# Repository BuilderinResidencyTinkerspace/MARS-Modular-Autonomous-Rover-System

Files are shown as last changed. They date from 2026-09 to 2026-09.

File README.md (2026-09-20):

# MARS — Modular Autonomous Rover System 🤖

> **One rover. Multiple capabilities.**

MARS (**Modular Autonomous Rover System**) is a modular robotic platform developed to explore how a single autonomous rover can be adapted for different real-world applications through interchangeable modules.

The project started with a simple question:

> **Instead of building a different robot for every task, can one rover be designed to perform multiple tasks by changing its module?**

This idea led to the development of a common rover base with autonomous movement, obstacle detection, wireless control, and interchangeable application-specific modules.

---

## 🚀 Project Overview

MARS consists of two main parts:

```text
                 ┌──────────────────────┐
                 │      MARS BASE       │
                 │      ROVER           │
                 │                      │
                 │ • Autonomous Motion  │
                 │ • Obstacle Detection │
                 │ • Wireless Control   │
                 │ • Modular Interface  │
                 └──────────┬───────────┘
                            │
             ┌──────────────┴──────────────┐
             │                             │
             ▼                             ▼
   ┌───────────────────┐       ┌────────────────────┐
   │ Raspberry Pi      │       │ Environmental      │
   │ Camera Module     │       │ Monitoring Module  │
   │                   │       │                    │
   │ • Webcam          │       │ • Gas Sensor       │
   │ • Live Streaming  │       │ • Soil Moisture    │
   │                   │       │ • Temperature      │
   └───────────────────┘       │ • Humidity         │
                               │ • Servo Mechanism  │
                               └────────────────────┘
```

The **base rover** provides mobility and autonomous navigation, while application-specific modules extend its functionality.

---

## 🎯 Objectives

The main objectives of MARS are:

* Develop a functional autonomous rover platform.
* Implement obstacle detection and avoidance.
* Enable wireless control of the rover.
* Develop a modular mechanism for attaching different application modules.
* Explore Raspberry Pi-based vision and remote monitoring.
* Develop an environmental sensing module.
* Integrate mechanical, electronic, and software systems into a single platform.
* Create a flexible platform that can be adapted for different field applications.

---

## 🛠️ Hardware

### Base Rover

| Component | Purpose |
| --- | --- |
| Arduino Uno | Main controller |
| DC Geared Motors | Rover movement |
| Motor Driver | Motor control |
| 14.8 V Battery | Main power source |
| Buck Converter | Voltage regulation |
| Ultrasonic Sensors | Obstacle detection |
| Bluetooth Module | Wireless control |
| 65 mm Universal Hub Tyres | Rover movement |
| Perfboard | Permanent circuit |
| 3D-Printed Chassis | Mechanical structure |

### Camera Module

| Component | Purpose |
| --- | --- |
| Raspberry Pi | Processing and streaming |
| Webcam | Live video capture |

### Environmental Monitoring Module

| Component | Purpose |
| --- | --- |
| Arduino Nano | Module controller |
| Gas Sensor | Gas detection |
| Soil Moisture Sensor | Soil moisture measurement |
| Temperature & Humidity Sensor | Environmental monitoring |
| Servo Motor | Raises/lowers the soil moisture sensor |

---

## ⚙️ Base Rover

The base rover went through several stages of development.

### 1. Initial Prototype

The first prototype was built using a temporary foam-board base. This allowed the basic components and movement system to be tested before developing the final mechanical structure.

### 2. Controller and Communication

The project initially used an **ESP32-S3** because of its built-in Wi-Fi capability.

During testing, the ESP32-S3 was damaged following a short circuit. We then adapted the rover to an **Arduino Uno**.

Since the Arduino Uno does not have built-in Wi-Fi, the communication system was changed from Wi-Fi-based control to **Bluetooth control**.

```text
Bluetooth Serial Terminal
            ↓
      Bluetooth Module
            ↓
        Arduino Uno
            ↓
       Motor Driver
            ↓
          Motors
```

### 3. Obstacle Detection

Three ultrasonic sensors were used at the front of the rover.

The sensors were arranged approximately as:

```text
             Front
               ↑

       \       |       /
        \      |      /
       +25°   0°   -25°

       Ultrasonic Sensors
```

This arrangement was tested to improve obstacle detection coverage in the direction of movement.

### 4. Autonomous Movement

The rover was developed to:

* Move forward
* Move backward
* Turn left
* Turn right
* Stop when an obstacle is detected
* Continue movement after the obstacle is removed

We also experimented with **point-to-point movement using a predefined room map**, testing movements such as A → B.

---

## 🔧 Mechanical Development

The mechanical structure evolved throughout the project.

The initial prototype used a **30 × 30 cm foam-board base**. Later, a more compact 3D-printed structure was developed with approximate dimensions of **21 × 18 cm**.

The CAD structure included provisions for:

* Battery mounting
* Ultrasonic sensor mounting
* Electronic component placement
* Module integration

The design was developed using **Zoo Keeper and Fusion 360**, followed by 3D printing and physical testing.

---

## 🔌 Electrical Development

The rover initially used a breadboard for temporary connections.

As the design became more stable, the circuit was transferred to a **perfboard**.

```text
Breadboard Prototype
        ↓
Component Testing
        ↓
Circuit Verification
        ↓
Perfboard
        ↓
Soldering & Wiring
        ↓
3D-Printed Integration
```

The permanent circuit contains the main control, communication, sensing, motor-control, and power-regulation components.

---

# 🧩 Application Modules

The modular architecture is the main concept behind MARS.

Instead of modifying the entire rover for every application, different modules can be attached to the same base platform.

## 📷 1. Raspberry Pi Camera Module

A Raspberry Pi and webcam were integrated as a separate module to provide **live video streaming**.

The development involved learning the Raspberry Pi setup process, including:

* Operating system installation
* Initial configuration
* Connecting the Raspberry Pi
* Connecting the webcam
* Network configuration
* Live video streaming

### System Flow

```text
       Webcam
          ↓
    Raspberry Pi
          ↓
      Wi-Fi Network
          ↓
    Live Video Stream
          ↓
     Remote User
```

This module can be used for applications such as:

* Remote inspection
* Surveillance
* Visual monitoring
* Disaster-area observation

---

## 🌱 2. Environmental Monitoring Module

The second module was developed using an **Arduino Nano**.

It combines multiple sensors to collect environmental information.

### Sensors

* Gas sensor
* Soil moisture sensor
* Temperature sensor
* Humidity sensor

A **servo motor** was also incorporated to mechanically raise and lower the soil-moisture sensor when required.

```text
Gas Sensor ─────────────┐
                        │
Soil Moisture Sensor ───┤
                        │
Temperature/Humidity ───┤
                        ↓
                    Arduino Nano
                        │
                        ↓
                   Sensor Data

                  Servo Motor
                       ↓
          Raise / Lower Moisture Sensor
```

This module demonstrates how MARS can be adapted for environmental monitoring applications.

---

# 📅 Development Timeline

| Week | Major Development |
| --- | --- |
| **Week 0** | MARS concept, system architecture and component planning |
| **Week 1** | Initial rover prototype and component procurement |
| **Week 2** | Component testing, 3D-printing and PCB design learning |
| **Week 3** | ESP32-S3 integration, Wi-Fi control and obstacle detection |
| **Week 4** | Autonomous movement experiments and sensor arrangement |
| **Week 5** | ESP32-S3 failure, Arduino Uno adaptation and Bluetooth control |
| **Week 6** | Ultrasonic integration, point-to-point navigation and CAD development |
| **Week 7** | New tyres, perfboard conversion and 3D-printed integration |
| **Week 8** | Permanent electrical system and room-based sensor testing |
| **Week 9** | Raspberry Pi camera module and environmental monitoring module |

---

# 🧠 Key Learning

The development of MARS involved learning across multiple areas:

### Electronics

* Motor drivers
* DC motor control
* Ultrasonic sensing
* Voltage regulation
* Battery-powered systems
* Perfboard soldering
* Sensor integration

### Embedded Systems

* Arduino Uno
* Arduino Nano
* ESP32-S3
* Bluetooth communication
* Wi-Fi communication
* Sensor interfacing

### Raspberry Pi

* OS installation
* Initial configuration
* Peripheral connections
* Webcam integration
* Network configuration
* Live video streaming

### Mechanical Design

* CAD modelling
* 3D printing
* Mechanical tolerances
* Component mounting
* Chassis design
* Module integration

### Robotics

* Obstacle detection
* Autonomous movement
* Point-to-point navigation
* Environmental sensing
* Modular robotic architecture

---

# 📂 Repository Structure

```text
MARS-Modular-Autonomous-Rover-System/
│
├── README.md
│
├── docs/
│   ├── week-00.md
│   ├── week-01.md
│   ├── week-02.md
│   ├── week-03.md
│   ├── week-04.md
│   ├── week-05.md
│   ├── week-06.md
│   ├── week-07.md
│   ├── week-08.md
│   └── week-09.md
│
├── code/
│   ├── base-rover/
│   ├── obstacle-avoidance/
│   ├── bluetooth-control/
│   ├── raspberry-pi-camera/
│   └── environmental-module/
│
├── cad/
│   ├── rover-base/
│   └── modules/
│
├── images/
│   ├── base-rover/
│   ├── camera-module/
│   └── environmental-module/
│
└── circuit/
    └── perfboard/
```

---

# 🔮 Future Improvements

Possible future developments for MARS include:

* Improved autonomous navigation
* More accurate mapping
* GPS-based outdoor navigation
* Better obstacle avoidance algorithms
* Wireless sensor-data transmission
* Additional application modules
* Improved modular attachment mechanism
* Battery monitoring
* Remote monitoring dashboard
* Integration of computer vision
* Autonomous task-based module selection

---

# 👥 Project

**MARS — Modular Autonomous Rover System**

Developed as a collaborative engineering project with a focus on **robotics, embedded systems, IoT, mechanical design, and modular architecture**.

The project documentation records the development process, challenges, design decisions, testing, and learning throughout the build.

---

> **MARS is not just a rover. It is a platform designed to become different robots for different tasks.**

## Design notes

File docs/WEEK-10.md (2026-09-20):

# Week 10: Calibration and Final System Testing

After developing the two application-specific modules in Week 9, the main focus this week was **calibration and testing**. At this stage, the major components of MARS were already working, but getting everything to work reliably together required repeated testing and adjustment.

## Calibrating the Rover

A significant part of the week was spent calibrating the rover's sensors and movement system.

The ultrasonic sensors were tested repeatedly to ensure that their distance measurements were consistent and suitable for obstacle detection and navigation. We also checked the rover's movement and made adjustments wherever necessary so that its actual movement matched the expected behaviour.

```text
Sensor Readings
      ↓
   Calibration
      ↓
      Test
      ↓
  Identify Error
      ↓
   Adjustment
      ↓
     Retest
```

This process had to be repeated several times. Small differences in sensor readings, motor movement, positioning, and the physical arrangement of components could affect the rover's overall performance.

## Calibrating the Modules

The application-specific modules also required testing and calibration.

The **Raspberry Pi camera module** was tested to ensure that the camera and live-streaming system were functioning correctly.

The **Arduino Nano environmental sensing module** was also tested with its gas, soil-moisture, and temperature-humidity sensors. The servo mechanism used to raise and lower the soil-moisture sensor was checked to ensure that it operated correctly when required.

Each part had to be tested individually and th137c8a32-267c-4a9f-98a1-5b03bfaf553c
e
3285b010-125c-4593-889c-c6c8123289a0
0b09c2b5-f6ea-4e95-870e-322cbab6b999

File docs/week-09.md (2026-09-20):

# Week 9: Bringing the Modular Concept to Life

After completing the main base rover and integrating its electrical and mechanical systems, Week 9 was focused on demonstrating what made MARS different from a conventional rover: **the ability to perform different tasks by changing its modules**.

This week, we developed two different modules. The first focused on **remote visual monitoring using a Raspberry Pi and webcam**, while the second was designed for **environmental sensing** using an Arduino Nano.

## Raspberry Pi Camera Module

The first module was built using a **Raspberry Pi and a webcam** to provide the rover with a visual monitoring capability.


Setting up the Raspberry Pi was itself a learning process. I worked through the process of installing the operating system, configuring the Raspberry Pi, connecting it to the required network, and learning how to interface the webcam with it.

Once the setup was completed, we developed a **live video streaming system**. The webcam connected to the Raspberry Pi could capture video and stream it remotely, allowing the rover to be used for applications such as **remote inspection and surveillance**.

```text id="rpi7m2"
Webcam
   ↓
Raspberry Pi
   ↓
Wi-Fi Network
   ↓
Live Video Stream
   ↓
Remote User
```




Working with the Raspberry Pi also introduced me to a different type of development compared with the Arduino-based rover. From installing the OS and configuring the system to connecting peripherals and setting up the camera, I gained practical experience with the complete setup process.

## Environmental Sensing Module

The second module was designed for **environmental monitoring**.

We used an **Arduino Nano** as the controller and integrated multiple sensors to measure different environmental parameters:

* Gas sensor
* Soil moisture sensor
* Temperature and humidity sensor

  
  
 

This module was intended to allow the rover to collect environmental information while moving through an area.

```text id="7t8k2a"
Gas Sensor ─────────┐
                    │
Soil Moisture ──────┤
                    ↓
Temperature/Humidity → Arduino Nano
                    │
                    ↓
             Sensor Readings
```

## Adding a Servo Mechanism

We also added a **servo motor** to the environmental sensing module.

The servo was used to **raise and lower the soil-moisture sensor when required**. This allowed the sensor to be moved into position for taking measurements and then lifted when it was not needed.

This was an important addition because it demonstrated that a module could contain not only sensors but also **mechanical actuation** for carrying out a specific task.

## The Modular System Takes Shape

With these two modules, the original idea behind MARS became more tangible.

The base rover provided the common mobility platform, while different modules could give it different capabilities.

```text
                 MARS BASE ROVER
                       │
          ┌────────────┴────────────┐
          ↓                         ↓
 Raspberry Pi Camera          Environmental
      Module                     Module
          │                         │
     Live Video              Arduino Nano
     Streaming               ├── Gas Sensor
                             ├── Moisture Sensor
                             ├── Temp/Humidity
                             └── Servo Motor
```

The Raspberry Pi module demonstrated **remote visual monitoring**, while the Arduino Nano module demonstrated **environmental data collection and sensing**.

## Challenges and Learning

The main learning experience this week came from working with hardware that was different from the electronics used in the base rover.

Working with the Raspberry Pi required learning the setup process from the beginning, including **OS installation, configuration, peripheral connections, networking, and camera streaming**.

At the same time, developing the Arduino Nano-based module required integrating several sensors and coordinating them with the servo mechanism.

This week showed us that the modular architecture could actually be used to extend the rover's functionality without redesigning the entire base system.

## Next Steps

With the first two application-specific modules developed, the next focus would be on **testing their integration with the MARS base rover**, improving their physical mounting, and ensuring that the modules can be attached and operated reliably.

Week 9 was therefore a major milestone for MARS: the project had moved beyond simply building an autonomous rover and had started demonstrating the idea of **one common rover platform supporting multiple specialized applications**.

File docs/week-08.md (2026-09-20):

# Week 8: From a Prototype to a Fully Integrated Rover

After spending the previous weeks developing the rover's mechanical structure and transferring the temporary wiring to a perfboard, Week 8 focused on **testing the permanent electrical system and integrating the complete rover**.

The next challenge was no longer simply getting individual components to work. We needed to make sure that all the components could operate together reliably inside the 3D-printed structure before moving towards mapping and autonomous navigation.

## Finalizing the Electrical System

We started the week by testing the completed **perfboard circuit**. Since the connections were now permanently soldered, each part of the circuit had to be checked carefully to make sure there were no incorrect connections or short circuits.

The perfboard contained the main electronic components of the rover:

* Arduino Uno
* Buck converter
* Bluetooth module
* Ultrasonic sensors
* Motor driver
* Motor connections

After checking the individual connections, we powered the system using the **14.8 V battery** through the required power arrangement.

We then tested the communication between the **Arduino Uno and Bluetooth module**, followed by the motor driver and motors. The rover was able to respond to commands and move correctly with the new permanent wiring.


## Integrating Everything into the 3D-Printed Base

Once the electrical system was verified, we mounted the perfboard and other components inside the **3D-printed rover base**.

This required careful positioning because the available space was limited. The components had to be arranged so that the wiring remained compact while avoiding interference with the mechanical parts of the rover.

The goal was to move away from the earlier breadboard-based prototype and create a more **compact, organized, and reliable base rover**.

```text
14.8 V Battery
       ↓
  Power System
       ↓
  ┌───────────────┐
  │   Perfboard   │
  │               │
  │ Arduino Uno   │
  │ Buck Converter│
  │ Bluetooth     │
  │ Motor Driver  │
  └───────────────┘
       ↓
     Motors

Ultrasonic Sensors
       ↓
   Arduino Uno
```

## Testing the Ultrasonic Sensors in a Real Environment

With the major components integrated, we turned our attention to the **ultrasonic sensors**.

Until this point, much of the sensor testing had been carried out during development. We now needed to understand how the sensors behaved in an actual room environment because their measurements would eventually be used for **mapping and autonomous navigation**.

We placed the rover at different positions and tested the sensors at different distances from walls and other obstacles. We compared the measured distances and observed how the readings changed depending on the sensor's position and the surrounding environment.

This was important because even a small error in distance measurement could affect where the rover believed an obstacle was located. Since the planned mapping system would depend on these measurements, we needed to understand and improve the accuracy before moving forward.


## From Testing to Mapping

The room-based testing also helped us identify minor issues with **wiring, sensor positioning, and component placement**. These were corrected before moving towards the mapping stage.

The development process was now becoming clearer:

```text
Component Testing
       ↓
Permanent Perfboard
       ↓
3D-Printed Integration
       ↓
Sensor Calibration
       ↓
Room Testing
       ↓
Mapping
       ↓
Autonomous Navigation
```

This week therefore represented an important transition. The rover was no longer just a collection of tested components or a temporary prototype. It was becoming a **single integrated platform**, ready for the next stage of autonomous navigation.

## Challenges and Decisions

The main challenges were checking the large

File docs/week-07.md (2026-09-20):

# Week 7: Moving from a Temporary Prototype to a Reliable Rover

After developing the autonomous movement and 3D-printed structure in Week 6, our focus this week was to make the rover **more stable, reliable, and organized**. The temporary breadboard setup also needed to be replaced with a more permanent arrangement.

## Improving the Mechanical Setup

We replaced the existing tyres with **65 mm Universal Hub tyres**. The new tyres provided better compatibility with the motors and improved the overall stability and movement of the rover.

We also 3D printed the remaining CAD-designed parts and began arranging the components within the structure. The **Arduino Uno, motor driver, battery, and other components** were positioned according to the planned layout.

This allowed us to check whether the available space was sufficient and whether the wiring and mechanical components could coexist without interfering with the rover's movement.
- 

- 
## Moving to a Perfboard

The previous breadboard connections were temporary, so we began transferring the circuit to a **perfboard**.

Each connection had to be soldered and checked individually. Since there were many wires in a limited space, arranging them neatly while avoiding short circuits and loose connections was a major part of the work.

After completing the soldering, we tested the connections to verify that the components were properly connected and functio

- 

- Photos :
  


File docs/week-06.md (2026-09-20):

# Week 6: Autonomous Movement and the First CAD Structure

After adapting the rover to the Arduino Uno in Week 5, this week we focused on **autonomous movement** and began developing the final mechanical structure of the base rover.

## Developing Autonomous Movement

We integrated the three ultrasonic sensors with the Arduino Uno and tested the rover's basic movements: **forward, backward, left, and right**.

When an obstacle was detected, the rover stopped and remained stationary until the obstacle moved away. It could then continue its movement.

To improve the detection coverage, the three ultrasonic sensors were arranged at the front in a curved configuration. The left and right sensors were positioned at approximately **+25° and -25°**, with the third sensor at the centre.


## Point-to-Point Navigation

We then worked on making the rover move between predefined points using a **map of the testing area**.

After providing the room dimensions and layout, we tested commands such as **A to B** and adjusted the movement several times to achieve the required path and positioning.

This helped us move from simple obstacle detection towards a more structured form of autonomous navigation.

## Developing the CAD Model

Alongside the electronics and programming, we started designing the base rover in **Zoo Keeper and Fusion 360**.

The base was designed at approximately **21 × 18 cm**, with dedicated spaces for:

* Battery holder
* Ultrasonic sensor holders
* Module integration area

After checking the dimensions of the physical components, we made several corrections to ensure that the parts would fit properly. The final design was then **3D printed**.

```text id="x3v8j7"
CAD Design
    ↓
Check Component Dimensions
    ↓
Make Corrections
    ↓
3D Printing
    ↓
Physical Rover Base
```

## Challenges and Next Steps

The main challenges this week were achieving accurate A-to-B movement and ensuring that the CAD dimensions matched the actual components.

By the end of the week, we had a working direction for autonomous movement and a first 3D-printed structure for the base rover.

Next week, we planned to:

* Improve autonomous movement and A-to-B navigation.
* Complete and test the 3D-printed base.
* Begin developing the module integration mechanism.
* Continue refining the CAD design based on testing.

Week 6 marked an important step from a temporary prototype towards a **structured autonomous rover platform**.

  

## Links
- https://zoo.dev/docs/zoo-design-studio/zookeeper
- CAD:


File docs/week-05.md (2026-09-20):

# Week 5: Adapting MARS After a Controller Failure

After working towards autonomous navigation in Week 4, this week brought an unexpected setback. A change in the power system led to the failure of the ESP32-S3, forcing us to reconsider the controller and communication system of the rover.

## The Controller Failure

We changed the battery to a **14.8 V battery** and began testing the motor driver. During testing, we noticed that the two motor-driver channels were not receiving equal voltage, so we started troubleshooting the system.

While the battery was connected during this testing, a **short circuit occurred and damaged the ESP32-S3**. Since the controller was an important part of the rover's control system, we needed to find an alternative quickly.


## Moving to Arduino Uno

After considering the available options, we decided to replace the ESP32-S3 with an **Arduino Uno**.

However, this was not simply a controller replacement. The change required us to modify the **wiring, code, and communication system** to suit the new controller.

The Arduino Uno also does not have built-in Wi-Fi, so the previous local-host control system could no longer be used. We therefore shifted to **Bluetooth communication**, using a Bluetooth Serial Terminal app to send movement commands to the rover.

```text
Bluetooth Serial Terminal
          ↓
      Bluetooth
          ↓
      Arduino Uno
          ↓
     Motor Driver
          ↓
        Motors
```

## Getting the Rover Moving Again

After rewiring the rover and modifying the code, we tested the Bluetooth-controlled movement.

The rover was able to respond to commands and perform the basic movements successfully. However, the ultrasonic sensors had not yet been integrated with the Arduino Uno, so autonomous obstacle avoidance was temporarily put on hold.

This week showed us that hardware changes can affect the entire system, not just a single component. We had to adapt both the electrical and software sides of MARS to continue development.

## Next Steps

The next stage would focus on:

* Integrating the ultrasonic sensors with the Arduino Uno.
* Implementing autonomous obstacle avoidance.
* Testing the sensors while the rover is moving.
* Improving the Bluetooth control system.
* Working towards combining remote control with autonomous operation.

The main objective was now to **stabilize the new Arduino-based system and continue towards autonomous navigation**.





## Links

- Photos
  


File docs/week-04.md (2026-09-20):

# Week 4: Moving Towards Autonomous Navigation

After giving MARS wireless control and basic obstacle detection in Week 3, the next goal was to make the rover **operate more autonomously**. We wanted it to not only detect obstacles but also move between different points without continuous manual control.

## Developing Obstacle Avoidance

Initially, we planned to place three ultrasonic sensors at the **front, left, and right** sides of the rover so that it could detect obstacles from multiple directions.

However, during testing, this arrangement did not provide reliable obstacle avoidance. The rover did not always respond as expected, which showed that the sensor arrangement needed to be reconsidered.

After testing different configurations, we decided to place **all three ultrasonic sensors at the front**. This provided better coverage in the direction of movement and was more suitable for our current obstacle avoidance approach.

## Planning Point-to-Point Movement

We also started working towards a system that could allow the rover to move from one location to another without continuous manual control.

Our approach was to combine **path following with obstacle avoidance**. The idea was for the rover to follow a predefined path while using ultrasonic sensors to detect and respond to obstacles.

To plan this system, we measured the **room dimensions and the intended testing path**. These measurements helped us understand the environment in which the rover would operate.
- 

## Fixing the Wheel Problem

We also returned to the wheel connection problem from the previous week. After making the necessary adjustments, the wheels were properly attached to the motors, allowing the rover to move correctly.

This removed one of the major mechanical issues and allowed us to focus more on autonomous navigation.

## Next Steps

By the end of the week, we had a better understanding of the limitations of our initial sensor arrangement and had established a direction for autonomous movement.

The next stage would focus on:

* Developing the path-following system.
* Integrating path following with obstacle avoidance.
* Testing point-to-point movement.
* Further improving the three-front-ultrasonic configuration.

The rover was gradually moving from being **remotely controlled to making movement decisions based on its environment**.

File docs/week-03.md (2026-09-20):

# Week 3: Giving MARS Wireless Control and Obstacle Detection

After testing the individual components in Week 2, we began integrating them into the base rover. This week marked an important transition from testing individual parts to making the rover **function as a connected system**.

## Integrating the Rover

We connected the **ESP32-S3, motor driver, DC motors, ultrasonic sensor, and other required components** and started working on the rover's control system.

The ESP32-S3's built-in Wi-Fi was then used to create a **local host interface** through which the rover could be controlled wirelessly. We tested basic movement commands, and the rover was able to move according to the commands sent through the interface.

## Adding Obstacle Detection

We also implemented basic **ultrasonic-based obstacle detection**.

When an obstacle was detected in front of the rover, it would stop and wait until the obstacle was removed before continuing. After testing the system, both the wireless control and basic obstacle detection were functioning as expected.

```text
Wi-Fi Control
      ↓
   ESP32-S3
      ↓
  Motor Driver
      ↓
     Motors

Ultrasonic Sensor
      ↓
   ESP32-S3
      ↓
Obstacle Detected → Stop
```


## Starting the Mechanical Design

Alongside the electronics, we began planning the mechanical structure of the rover. Before moving into detailed CAD modelling, we created **rough paper sketches** to determine the positioning of the motors, wheels, and other components.

However, we faced a mechanical issue: **the wheels were not attaching properly to the motors**. This meant that the motor and wheel mounting arrangement needed further adjustment before the base structure could be finalized.



## Decisions and Next Steps

Based on this week's work, we decided to continue using the **ESP32-S3 Wi-Fi** for wireless control and the local host as the control interface. Ultrasonic-based obstacle detection was also retained as part of the base rover.

For the mechanical design, we planned to improve the motor and wheel mounting and then proceed with the detailed CAD design.

The next stage would focus on **improving the mechanical structure while continuing the integration of the rover's electronics and control system**.

-Photos


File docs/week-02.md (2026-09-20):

# Week 2: From Individual Components to an Integrated Design

After building the initial physical base of the rover in Week 1, the next challenge was to make sure that the components we had purchased were actually ready to be integrated. Instead of immediately assembling everything together, we decided to first understand and test each component individually.

At the same time, this week introduced us to an important part of the project that we had not worked with much before: **designing the mechanical and electronic systems that would eventually hold the rover together.**

## Testing the Building Blocks

The main focus of the week was testing the components purchased for the base rover. We tested the major components individually, including the **ESP32-S3, ultrasonic sensors, motor driver, DC motors, buck converter, battery, and other supporting components**.

The purpose of this approach was straightforward: before connecting several components together, we needed to verify that each one was functioning correctly.

This also gave us an opportunity to understand the characteristics and requirements of the individual components. In particular, we spent more time studying the **ESP32-S3**, since it would act as the main controller of the rover.

> **Before integrating the system, we first needed to understand the individual building blocks.**

Testing the components separately would also make future troubleshooting easier. If a problem occurred during integration, we would have a better idea of which components had already been verified and which part of the system needed to be investigated.



## Learning About 3D Printing

Another important part of this week was learning how 3D printing could be used in the mechanical development of MARS.

We had a discussion with **Kurian, COO of TinkerSpace**, who introduced us to the fundamentals of 3D printing and explained how the design of a part affects the final printed result.

One of the important concepts discussed was **tolerance**.

A dimension specified in a CAD model does not always translate into exactly the same physical dimension after printing. Factors such as the printer, material, layer settings, and design itself can affect the final dimensions.

This was particularly relevant to MARS because we planned to use 3D-printed parts for components such as motor mounts and other mechanical structures. Understanding tolerances at this stage would help us avoid problems when assembling parts later.




## Introduction to PCB Designing

We were also introduced to the basics of **PCB designing**.

Kurian explained the general process of converting an electronic circuit into a PCB and introduced us to **KiCad**, which we decided to use as we progressed with the project.

Until this point, our electronic connections were mainly being considered at the individual component and wiring level. Learning about PCB design helped us start thinking about how these connections could eventually be organized into a more permanent and structured system.

The overall process can be viewed as:

```text
Circuit Idea
     ↓
Schematic
     ↓
PCB Layout
     ↓
Fabrication
     ↓
Physical PCB
```

This became particularly important because the final rover would contain multiple electronic components that would need to communicate and receive power reliably.

## Learning From Existing Projects

During the session, Kurian also shared and explained some of the projects he had previously worked on.

Seeing these projects helped us understand how **electronic, mechanical, and software components come together in practical systems**. It also gave us a better perspective on the design process beyond individual components.

For MARS, this reinforced the importance of considering the complete system rather than developing the electronics, mechanical structure, and software independently.

## The Main Challenges

This week did not involve a major mechanical assembly milestone. Instead, the main challenge was building the knowledge required for the next stage of development.

Some components needed to be tested individually before they could be integrated into the rover. At the same time, we needed to become familiar with PCB design and 3D printing before beginning our own designs.

The concept of **3D-printing tolerances** was particularly important. A mechanical part that looks correct in a CAD model may not fit as expected after printing if manufacturing tolerances are not considered.

Therefore, the testing and learning carried out this week were not separate from the rover development. They were preparation for the integration stage that would follow.

## Decisions Made This Week

Based on the work and discussions during the week, we made several decisions for the next stages of MARS:

* Major components would be **tested individually before integration**.
* **KiCad** would be used for PCB design as the project progressed.
* 3D-printing tolerances would be considered while designing mechanical components.
* The ESP32-S3 would continue to be studied in greater detail to understand its capabilities and requirements.
* Mechanical and electronic design would be developed alongside the physical rover rather than being treated as separate stages.

## What Comes Next

With the individual components being tested and the basics of PCB design and 3D printing understood, the next step was to begin developing the rover's structure around these components.

The plan for the coming week was to:

* Continue developing the base structure of the rover.
* Start designing the motor mounting structure.
* Continue testing and integrating the electronic components.
* Begin the PCB design process using KiCad.
* Improve the mechanical parts based on the results of testing.

Week 2 was therefore less about making MARS perform a new function and more about **preparing the foundation for reliable integration**.

We had started with individual components, but the next challenge was to turn those components into a single working system.

## Links

-https://learn.pcbcupid.com/documentation/modules/glyph/glyph-esp32s3/glyph-s3-overview
-Photos


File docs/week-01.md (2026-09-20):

# Week 1: Turning the MARS Concept into a Physical Rover

Last week, MARS existed mostly as an idea—a modular rover platform designed around a common base that could eventually support different application-specific modules.

This week, the goal was much more straightforward:

**Start building the rover.**

After discussing the project concept and the requirements of the base platform, we moved from planning to the first physical prototype. Before worrying about autonomous navigation or application modules, we needed to establish a stable base on which everything else could be built.

---

## From a Concept to a Chassis

The first task was to create the physical base of the rover.

For the initial prototype, we decided to use **foam board** as the chassis material. It was lightweight, inexpensive, and easy to cut and modify during the early stages of development.

We cut the board to a size of **30 × 30 cm**, giving us a basic platform on which the motors, electronics, battery, and other components could eventually be mounted.

```text
              30 cm
       ┌──────────────────┐
       │                  │
       │    Rover Base    │
       │                  │ 30 cm
       │                  │
       └──────────────────┘
```

The intention was not to create the final mechanical structure immediately. At this stage, the foam-board chassis served as a practical prototype that allowed us to experiment with the component placement and overall dimensions of the rover.

 

---

## Getting the Hardware Together

Once the basic chassis was prepared, we began collecting the components required to build the base rover.

The initial hardware included:

| Component | Purpose |
| :--- | :--- |
| **ESP32-S3** | Main controller |
| **DC Motors** | Drive the rover |
| **Tyres** | Provide traction and movement |
| **Motor Driver** | Control the motors |
| **Ultrasonic Sensors** | Obstacle detection |
| **Battery** | Main power source |
| **Buck Converter** | Voltage regulation |

Having the major components physically available made the project feel significantly different from the previous week. We could now begin thinking about actual component placement, wiring, and mechanical assembly rather than only discussing the architecture.

---

## The Battery Holder Problem

The first practical obstacle appeared before we could even complete the power system.

We were unable to obtain a suitable battery holder for the battery we had selected. Since the rover required a **12 V supply**, we needed a way to establish a reliable connection between the battery and the rest of the system.

Instead of delaying the prototype, we decided to **solder the battery connections directly** to obtain the required power supply.

This allowed us to continue with the initial prototype, although it also highlighted an important consideration for the later stages of development: the final rover would need a safer and more convenient battery connection method.

```text
Battery
   │
   │  Direct soldered connection
   ↓
12 V Supply
   │
   ├────────→ Motor System
   │
   └────────→ Buck Converter
                    │
                    ↓
              Low-voltage electronics
```

The solution was therefore useful for getting the prototype running, but it was treated as a temporary arrangement rather than the final power architecture.

---

## The First Physical Version of MARS

By the end of the week, we had completed the first physical foundation of the rover.

It was still a very early prototype, but the transition was important. MARS had moved from a concept and system architecture into something that could actually be assembled and tested.

The 30 × 30 cm foam-board base provided the platform for the next stage, while the major electronic and mechanical components had been acquired.



---

## What We Learned This Week

The main lesson from this stage was that moving from a design concept to a physical prototype immediately introduces constraints that are difficult to identify on paper.

Component availability, mounting space, wiring, battery connections, and physical dimensions all started influencing the design.

The battery-holder issue was a small problem, but it demonstrated an important part of hardware development: **the planned design sometimes has to adapt to the components and resources that are actually available.**

For now, the temporary battery connection allowed us to continue building. The next challenge was to bring the individual components together and make the rover move.

---

## Next Week: Making It Move

With the basic platform and components ready, the next step was to begin assembling the actual drive system.

We planned to mount the **DC motors and tyres**, install the **motor driver and ESP32-S3**, and begin connecting the power system to the rover.

The first major milestone would be simple:

> **Make MARS move forward and backward.**

Once basic motor control was working, we could begin building towards turning, sensor integration, and eventually autonomous movement.

The rover had a chassis.

It had motors.

It had a controller.

Now we needed to make all of them work together.

  

- Photos


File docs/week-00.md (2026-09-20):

# Week 0: From a Rover Idea to MARS

The project started with a simple idea: building a rover.

At the beginning, I was interested in developing a mobile robotic system that could move autonomously using motors, sensors, and a microcontroller. However, as I started thinking about the project more deeply, one question became important:

**What would the rover actually be used for?**

A rover that could simply move around and avoid obstacles would demonstrate basic robotics concepts, but I wanted the project to have a more meaningful real-world purpose. This led me to think beyond the rover itself and explore the different situations where such a system could actually be useful.

That exploration eventually led to the concept of **MARS — Modular Autonomous Rover System**.

---

## Finding a Purpose for the Rover

I began considering different applications for a mobile robotic platform.

One possibility was **disaster search and assistance**, where a rover could be deployed in areas that may be unsafe for humans. Another was **material or package delivery**, where the rover could transport items to a specified location. **Remote inspection** was another potential application, particularly for environments that are difficult or dangerous for people to access.

However, these applications presented an interesting problem.

Each application would require different hardware.

A disaster-search rover might need a camera or additional sensing capabilities. A delivery rover would require a mechanism to carry and release materials. An inspection rover could require a completely different set of sensors.

Instead of developing a separate rover for every application, I explored the possibility of using **one common rover platform with interchangeable application-specific modules**.

The idea was simple:

> **The rover would remain the same, while its purpose could change depending on the module attached to it.**

This became the core concept behind MARS.

---

## The Modular Concept

The proposed system would consist of a common rover base containing the fundamental components required for movement and basic autonomous operation.

Application-specific functionality would be added through interchangeable modules.

```text
                     MARS
                      │
             ┌────────┴────────┐
             │                 │
        Common Base       Application Module
             │                 │
          Motors             Search
          Battery            Delivery
          Controller         Inspection
          Sensors            Other Tasks
          Chassis
```

This approach would allow the same rover to be adapted for different missions without having to redesign the complete robot each time.

For me, this was the key idea that made the project more interesting than simply building another autonomous rover. The goal was to develop a **flexible robotic platform** rather than a robot limited to one specific function.

---

## Defining the Base Rover

Once the modular concept was established, I started looking at what components would need to be common to every version of the rover.

The base platform was planned around a microcontroller, DC geared motors, a motor driver, battery system, obstacle-detection sensors, chassis, and a modular mounting mechanism.

The **ESP32-S3** was initially selected as the main controller. Its processing capability and wireless communication features made it suitable for the planned autonomous and IoT-related functionality.

For the initial obstacle-detection system, **ultrasonic sensors** were considered. These would provide distance measurements that could be used by the controller to detect obstacles and make basic movement decisions.

The initial architecture was therefore:

| Subsystem | Initial Selection | Purpose |
| :--- | :--- | :--- |
| **Controller** | ESP32-S3 | Main processing and control |
| **Drive System** | DC geared motors | Rover movement |
| **Motor Driver** | Motor driver | Motor control |
| **Sensors** | Ultrasonic sensors | Obstacle detection |
| **Battery** | Rechargeable battery | Main power source |
| **Power Regulation** | Buck converter | Regulated supply for electronics |
| **Chassis** | Rover chassis | Mechanical structure |
| **Module Interface** | Modular mounting system | Interchangeable modules |

---

## The Power Problem

One of the first technical challenges I identified was the power system.

The motors would require a considerably higher voltage than the ESP32-S3 and the sensors. This meant that the same battery supply could not simply be connected directly to every component.

A regulated power system would therefore be required.

```text
             Rechargeable Battery
                      │
             ┌────────┴────────┐
             │                 │
       Motor Supply       Buck Converter
             │                 │
       Motor Driver      Low-Voltage Rail
             │                 │
        DC Motors       ESP32-S3 + Sensors
```

The main battery would supply the motor system, while a buck converter would provide a suitable regulated voltage for the controller and sensors.

This made power management an important part of the system architecture from the beginning.

---

## Making the Rover Modular

The modular concept also introduced mechanical challenges.

The application modules needed to be securely mounted so that they would not become loose while the rover was moving. At the same time, they had to be removable so that different modules could be attached when required.

This meant that the mounting system would need to balance **mechanical stability and ease of replacement**.

The electrical interface also had to be considered. Different modules could require different power or communication connections, so the base rover needed to be designed with future modules in mind.

This was one of the aspects that made MARS different from a conventional autonomous rover: the base had to be designed not only for what it could do immediately, but also for what could be added to it later.

---

## Keeping the Project Realistic

Another important consideration was the available development time.

There were many possible features that could be added to MARS, but attempting to implement everything would make the project difficult to complete and test properly.

The development was therefore planned in stages:

```text
Base Chassis
      ↓
Motor & Drive System
      ↓
Power System
      ↓
Sensor Integration
      ↓
Basic Autonomous Movement
      ↓
Modular Interface
      ↓
Application Modules
```

The project scope was eventually planned around **two application-specific modules**. This would provide enough opportunity to demonstrate the modular concept while keeping the development and testing manageable.

The initial architecture was also kept flexible so that hardware choices could be modified if testing revealed better alternatives during the development process.

---

## What Made This Challenging

By the end of Week 0, the project had moved far beyond the original idea of simply building a rover.

The challenge was now to bring together **mechanical construction, motor control, power management, sensing, embedded programming, autonomous movement, and modular hardware** into one reliable system.

I started with a simple question:

> **“How can I build a rover?”**

But while exploring possible applications, that question changed into something more interesting:

> **“How can one rover be adapted to perform different real-world tasks?”**

That shift in perspective led to the concept of **MARS — Modular Autonomous Rover System**.

The next step was to move from the concept and architecture to the physical development of the rover base.

##Links

- https://gamma.app/docs/Modular-Autonomous-Rover-System-r9c271r7w8i100q



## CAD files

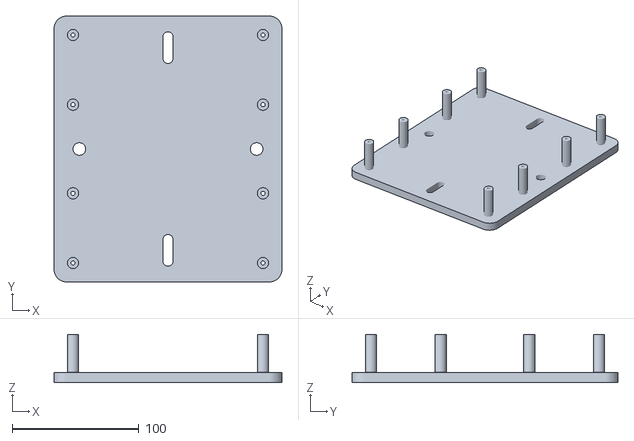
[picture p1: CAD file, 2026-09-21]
cad/LOWERDECK_RIZ.stl
180.0 x 210.0 x 38.0

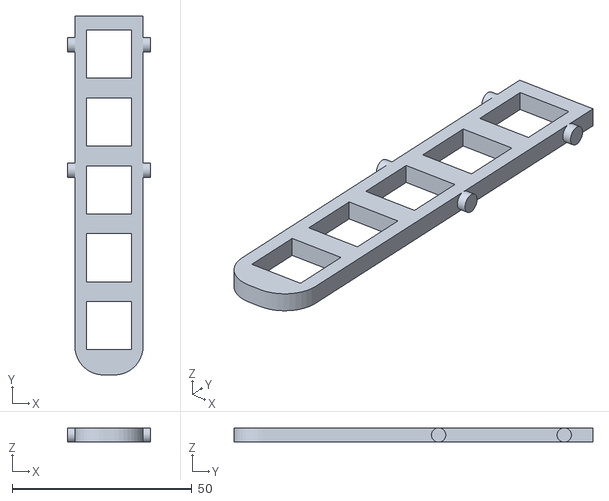
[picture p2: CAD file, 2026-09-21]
cad/RizA1S.STL
23.0 x 100.0 x 4.00

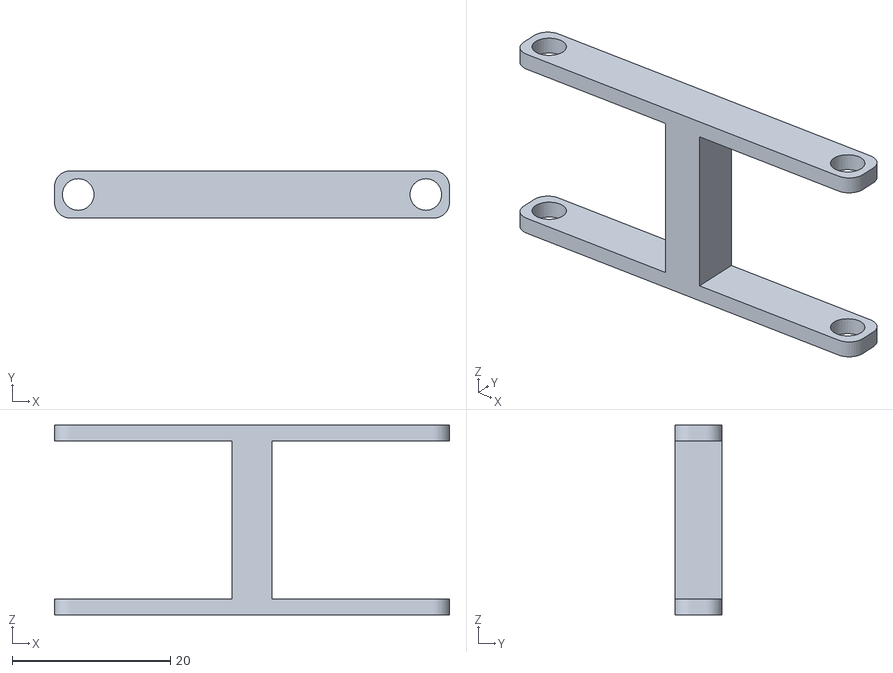
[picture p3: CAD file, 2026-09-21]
cad/RizA2S.STL
50.0 x 6.00 x 24.0

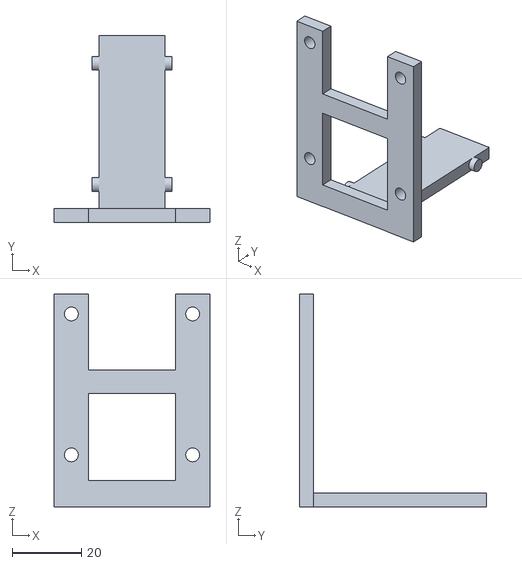
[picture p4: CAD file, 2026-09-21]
cad/RizA3S.STL
45.0 x 54.0 x 61.5

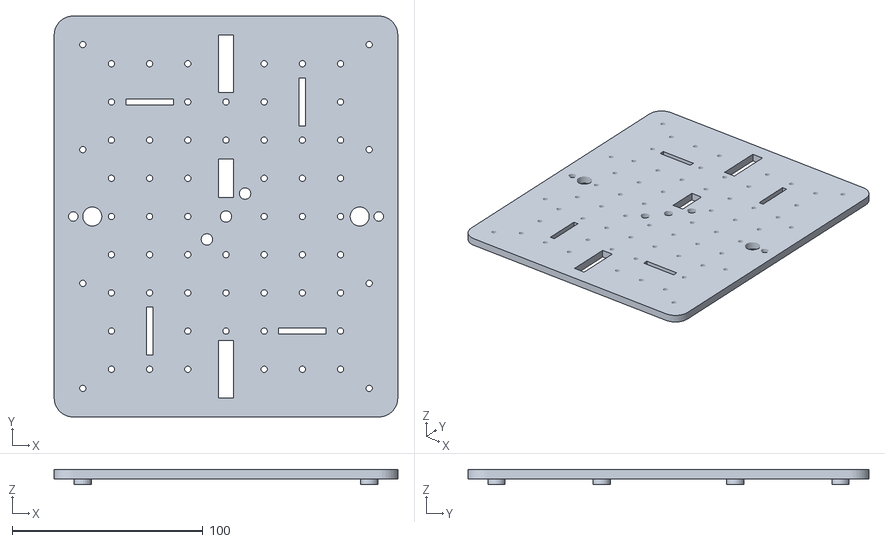
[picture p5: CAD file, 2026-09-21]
cad/UPPERDECK_RIZ.stl
180.0 x 210.0 x 8.00

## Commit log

2026-09-14 Revise Week 2 report with detailed activities and goals
    Updated the weekly report to include goals, activities, problems, decisions, and next steps related to testing components and learning about PCB design and 3D printing.
2026-09-14 Revise week 3 documentation with project updates
    Updated the week 3 documentation to include details on the integration of the rover components, wireless control, and obstacle avoidance system. Added notes on mechanical design planning and identified problems and decisions made during the week.
2026-09-14 Revise Week 4 goals and progress details
    Updated the goals and progress for Week 4, detailing the implementation of obstacle avoidance and path following for the MARS rover. Adjusted sensor placement and addressed wheel connection issues.
2026-09-14 Revise Week 5 project update and goals
    Updated the week's goals, activities, problems, decisions, and next steps regarding the rover project. Notable changes include replacing the damaged ESP32-S3 with an Arduino Uno and switching from Wi-Fi to Bluetooth for control.
2026-09-14 Update Week 6 progress on rover development
    Integrated ultrasonic sensors with Arduino Uno for autonomous movement and started CAD design for the rover base.
2026-09-17 Refine week-06 documentation and improve formatting
    Updated the week-06 documentation to improve clarity and remove formatting inconsistencies. Added images and refined descriptions of the ultrasonic sensor integration and CAD design process.
2026-09-20 From Individual Components to an Integrated Design
    Added images to illustrate 3D printing considerations and PCB designing.
2026-09-20 Giving MARS Wireless Control and Obstacle Detection
2026-09-20 Enhance rover stability and organization
    Improved the mechanical structure and reliability of the rover by replacing tyres, transitioning to a permanent perfboard setup, and organizing components within the 3D-printed design.
2026-09-20 Finalize electrical integration and sensor testing
    Integrated the electrical system into the 3D-printed rover base and tested components for functionality. Conducted room-based tests for ultrasonic sensors to ensure accurate measurements for mapping 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
2026-09-20 Add image for temperature and humidity sensor
    Added a new image for the temperature and humidity sensor.
2026-09-20 Add Week 10 documentation on calibration and testing
    Detailed the calibration and testing process for the rover and its modules, including sensor adjustments and individual module testing.
2026-10-12 Turning the MARS Concept into a Physical Rover
    Removed sections about lessons learned and battery connection issues, focusing on the next steps for assembling the drive system.
2026-10-12 Arduino Uno setup
    Detailed the transition process from ESP32-S3 to Arduino Uno, including necessary modifications to wiring and communication methods. Highlighted the shift to Bluetooth for command control due to the 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
2026-10-12 Autonomous Movement and the First CAD Structure
2026-10-12 From a Prototype to a Fully Integrated Rover
2026-10-12 Calibration and Final System Testing
